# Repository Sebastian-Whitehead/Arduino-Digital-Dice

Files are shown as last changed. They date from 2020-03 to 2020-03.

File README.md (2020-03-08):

# DIY Digital Dice (d10000)

	This is an Arduino based DIY digital dice that, as standard, can generate a random number between 0 and 4 /6 /8 /10 /12 /20 /100 /1000 *or* 10000 along with a coin flip between heads and tails (1/2.) Using a gyroscope the device can sense its rotational acceleration around any one of the three axis and generate a random number when a specified threshold is reached. Originally created to use along side with an extended 'chaos magic' in DnD 5e. Despite this the dice can function as a physical random number generator for any situation with little modification to the Arduino code if wanted.

### Prerequisites

###### Software:

- Access to a 3d printer (... *cm* x ... *cm* x ... *cm*  **min print size**) and slicer
- 3D modelling program *(Fusion 360)*
- Arduino IDE *(or other Arduino compatible IDE's)*
  - LiquidCrystal.h
  - Wire.h
- EDA software Autodesk 'Eagle' *(alternatively 'Easy EDA')*

###### Components [Standard]:

- Arduino Nano
- 8x2 liquid crystal display
- MPU-6050 Gyroscope
- 2x 10k Resistor *THT*
- 1x 10k potentiometer 
- 2x 100nF non polarized capacitor (5.8mm *THT*) 
- 1x Speaker
- 2x Momentary Buttons <u>[hole mountable]</u> 
- 1x Toggle Switch / Button <u>[hole mountable]</u> 
- 1x 1s rechargeable Lithium Polymer battery and USB charging circuit 
  *<u>(Easily found from butchering a 5v battery charger)</u>*
- 1x PCB (*see production files*)
- 1x 3D printed shell
- (screws, nuts and washers) ...

### Contributing

All contributions are accepted with no requirements for permission from authors.

### Version

Release 0.1 **[Board Design & Program]** (08.03.2020)

### Authors

- **Sebastian Whitehead** - *Initial work* [*Version 1.0*]

### License

This Project is licensed under the MIT License - See the LICENSE.md file for details

### Acknowledgments

-  Dejan - howtomechatronics.com - parts of the Gyroscope code

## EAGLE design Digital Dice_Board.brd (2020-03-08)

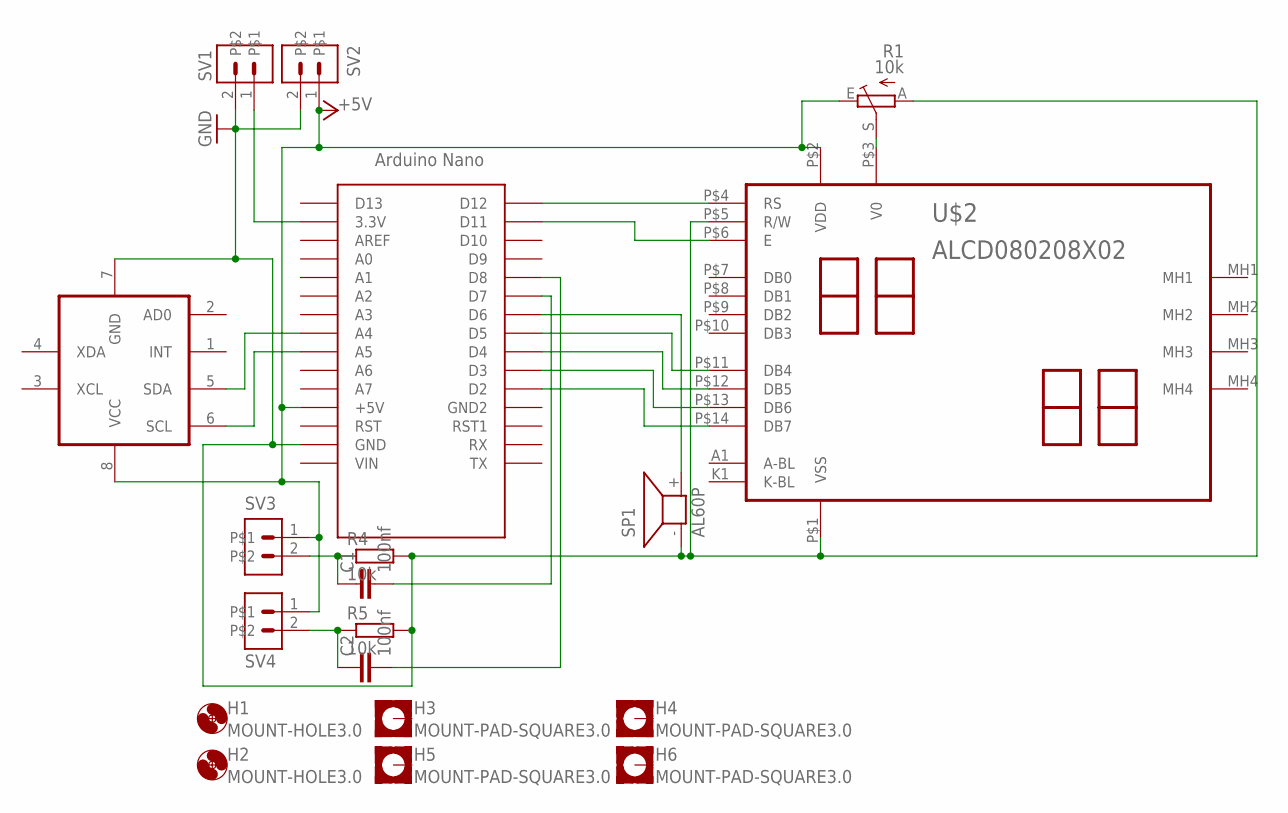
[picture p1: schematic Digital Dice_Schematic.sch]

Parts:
C1, C2: 100nf; C050-025X075W
H1, H2: MOUNT-HOLE3.0; 3,0
H3, H4, H5, H6: MOUNT-PAD-SQUARE3.0; 3,0-PAD-SQUARE
R1: 10k; CA9V
R4, R5: 10k; 0207/12
SP1: AL60P
SV1, SV2, SV3, SV4: MA02-1
U$1: NANO
U$2: ALCD080208X02; ALCD0802
X1: GYRO_MPU-6050; MPU

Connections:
+5V: R1.E, SV2.1, SV3.1, SV4.1, U$1.5V (+5V), U$2.P$2 (VDD), X1.8 (VCC)
GND: R1.A, R4.2, R5.2, SP1.- (1), SV1.2, SV2.2, U$1.GND, U$2.P$1 (VSS), U$2.P$5 (R/W), X1.7 (GND)
unnamed: U$1.D12, U$2.P$4 (RS)
unnamed: C2.1, R5.1, SV4.2
unnamed: U$1.A5, X1.6 (SCL)
unnamed: U$1.A4, X1.5 (SDA)
unnamed: R1.S, U$2.P$3 (V0)
unnamed: SV1.1, U$1.3.3V
unnamed: C1.1, R4.1, SV3.2
unnamed: U$1.D11, U$2.P$6 (E)
unnamed: U$1.D5, U$2.P$11 (DB4)
unnamed: U$1.D4, U$2.P$12 (DB5)
unnamed: U$1.D3, U$2.P$13 (DB6)
unnamed: U$1.D2, U$2.P$14 (DB7)
unnamed: SP1.+ (2), U$1.D6
unnamed: C1.2, U$1.D7
unnamed: C2.2, U$1.D8

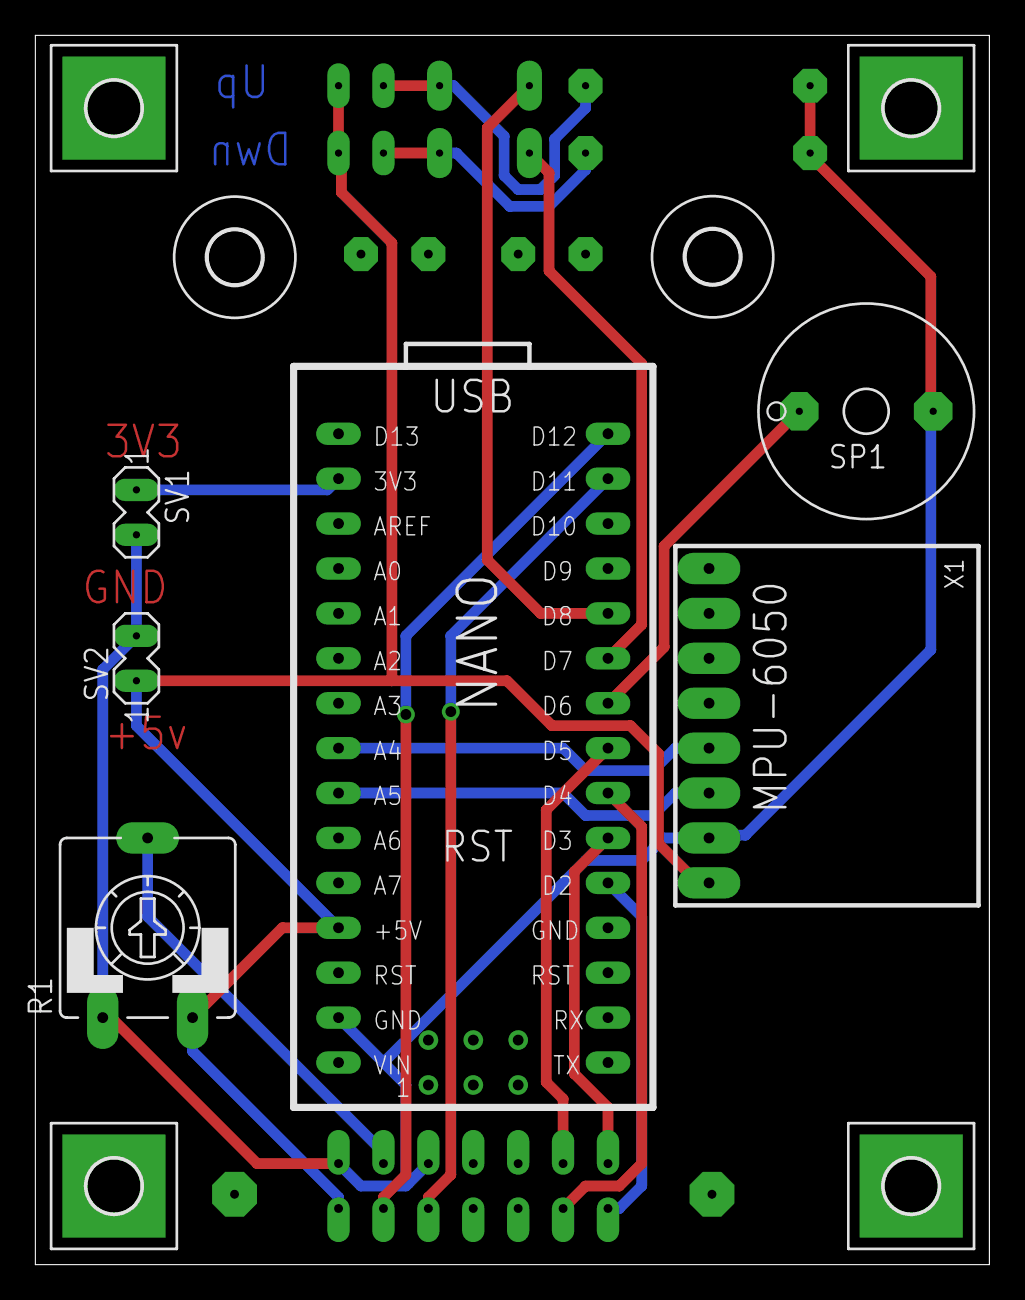
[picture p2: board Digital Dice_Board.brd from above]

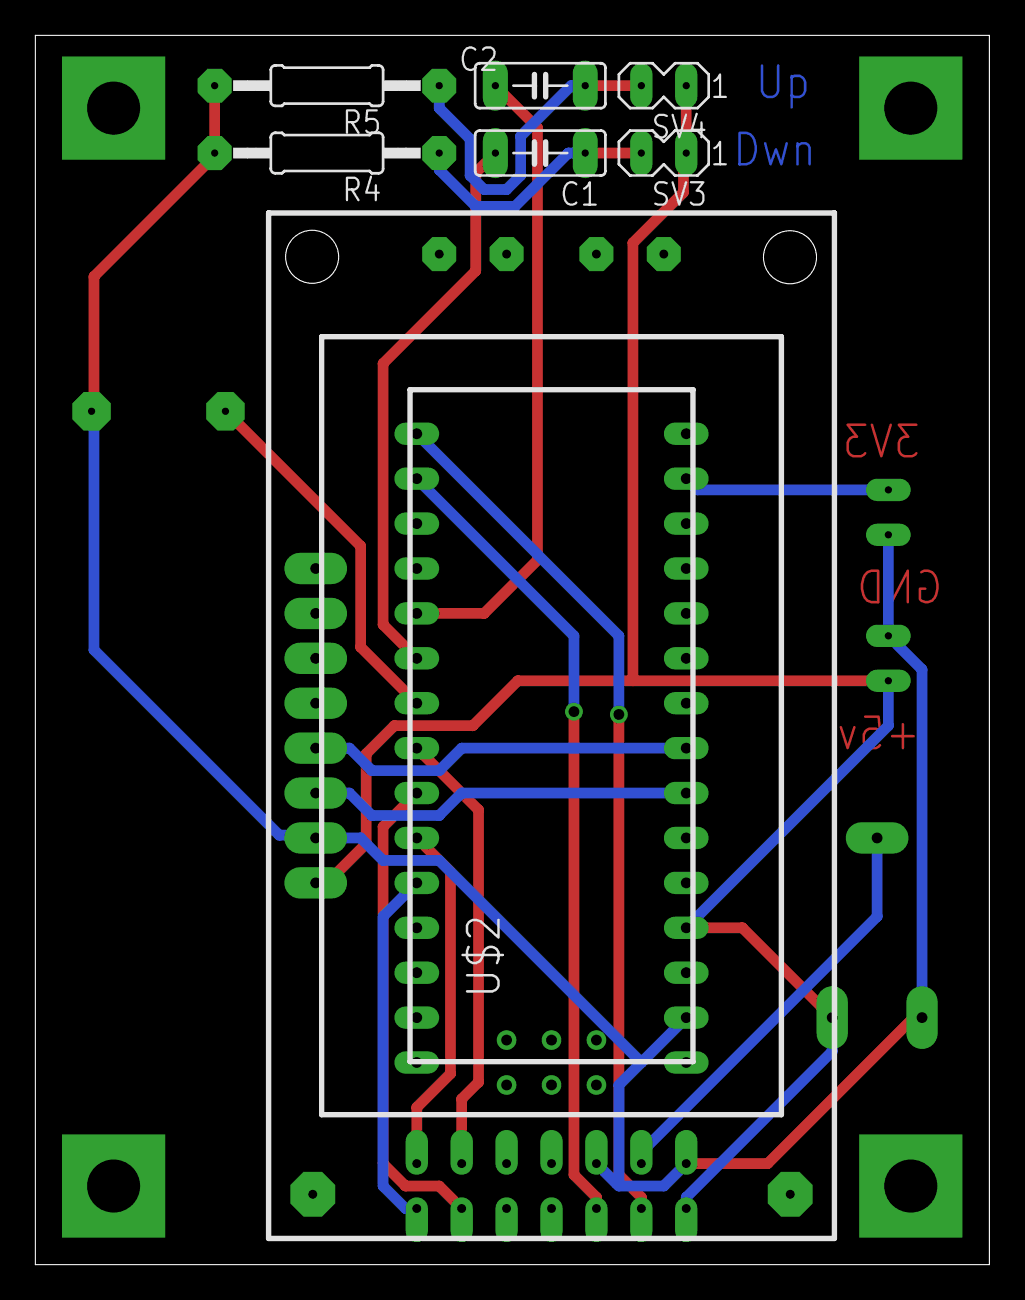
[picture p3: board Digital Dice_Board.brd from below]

Board: 2 copper layers, 54.0 x 69.5 mm, 19 parts (7 on the bottom side), 17 nets.

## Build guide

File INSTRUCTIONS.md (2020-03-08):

# Assembly Instructions

###### Tools

- Soldiering station (*possibly a hot air gun for heat shrink*)

- Screw driver and small wrench for mounting
- 3D printer (*alternatively order the model*)
- PC *with Arduino IDE installed*
- Mini-B USB cable
- Hot Glue Gun, Double Sided Tape & Zip Ties

###### Assembly

1. Order PCB using the included Gerber files 
2. Gather Compatible Electrical components for assembly 
   <u>(butcher a USB battery bank for the charging circuit)</u>
3. Modify the 3D model in order to accommodate you chosen components or as you see fit
4. Print the model components and gather the necessary mounting hardware  
5. If you have the tools to do so test the components before assembly with the 
   '*Digital Dice_ Arduino Program*'
6. Soldier all the components on the Arduino side of the board. 
7. Cut all excess leg length to make space for components on the other side of the board. 
8. Assemble and mount components on the opposite side of the PCB
   **NOTE: Put screws through the displays mounting holes with spacers in-between it and the PCB**
9. Adjust the screen contrast now as it will be difficult later
10. Mount the selection up and down buttons to the front panel and soldier their wires to the corresponding holes on the board
11. If necessary feed the power switch cables through the mounting hole 
    *(only necessary if the toggle switch is screwed in from the inside of the cube)*
12. Soldier the battery to the power switch and the corresponding 5v supply and ground holes on the PCB 
    *(There is 3v3 supply for backlit switches)*
13. Mount the PCB to the included screw holes making sure the black LCD bezel is aligned with the cut out 
14. Mount the power button and charging circuit to their corresponding locations.
15. Mount the LiPo battery cell to and adequate location
16. Charge, Power ON, Test
17.  **ENJOY!!** 

**WARNING!**	Make sure to take precautions when working with LiPo batteries as there are some inherent dangers that can arise. Preform this project at your own risk and if you make improvements or modifications for the project feel free to post them on the GitHub page for others to enjoy.

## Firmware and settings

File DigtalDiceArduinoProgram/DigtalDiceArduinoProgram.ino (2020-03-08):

/*
By: Sebastian Whitehead
Credit: Dejan (howtomechatronics.com) *Gyroscope code modified

==== Instructions ====
1. Shake to roll the dice (default d10000)
2. Use the buttons to cycle between the different dice types
3. To mute and unmute hold the selection up button until the 'Shake me' screen appears then release
4. Adjust the potentiometer to regulate text clarity

Distrobuted under the MIT license see LICENSE.md for more details
*/


#include <Wire.h>
#include <LiquidCrystal.h>

// == Pins == //
LiquidCrystal lcd(12, 11, 5, 4, 3, 2);
const int DownPin = 7;
const int UpPin = 8;
const int Speaker = 6;

// == Variables == //
const int MPU = 0x68;         // MPU6050 I2C address
float GyroX, GyroY, GyroZ;
long MaxRoll = 10001;         // Default Setting
int Dice = 9;                 // Number of dice types
long result = 0;              // Role result
unsigned long LastAction = 0; // Time of last screen effecting action
bool UpCompleted = false;     // Variables for preventing rapidly recurring presses
bool DownCompleted = false;
int MuteStart = 0;            // Start Time for mute function
int MuteStop = 0;             // Stop Time for mute function

// ==== Options ==== //
int IdleDelay = 30000;  // Standard delay before screen reverts to idle state
bool Mute = true; // Default Mute Setting



void setup() {
  Serial.begin(19200);
  pinMode(UpPin, INPUT);    //Button Pins
  pinMode(DownPin, INPUT);

  // Starting Gyro //
  Wire.begin();                      // Initialize comunication
  Wire.beginTransmission(MPU);       // Start communication with MPU6050 // MPU=0x68
  Wire.write(0x6B);                  // Talk to the register 6B
  Wire.write(0x00);                  // Make reset - place a 0 into the 6B register
  Wire.endTransmission(true);        // end the transmission
  delay(20);

  // Start LCD //
  lcd.begin(8, 2);

  // Starting Tune //
  tone(Speaker, 300);
  delay(250);
  tone(Speaker, 400);
  delay(250);
  tone(Speaker, 500, 250);
  idle(); // Idle Screen
}

void loop() {
  Gyro(); // Position sensing funktion
  if (millis() > LastAction + IdleDelay) { // Returns to idle after 30 seconds
    idle();
  }

  // ==== Push Button Up ==== //
  if (digitalRead(UpPin) == HIGH && UpCompleted == false) {
    Dice ++;
    Change();
    UpCompleted = true;
    MuteStart = millis();

    // ==== Release Button Up ==== //
  } else if (digitalRead(UpPin) == LOW && UpCompleted == true) {
    UpCompleted = false;
    MuteStop = millis();

    // == Long Press Mute Toggle == //
    if (MuteStop - MuteStart > 3000 && Mute == true) {
      Mute = false;
      lcd.clear();
      lcd.setCursor(0, 0);
      lcd.print("Unmuted");
    } else if (MuteStop - MuteStart > 3000 && Mute == false) {
      Mute = true;
      lcd.clear();
      lcd.setCursor(0, 0);
      lcd.print("  Muted");
    }
    IdleDelay = 3000;
    LastAction = millis();
  }

  // ==== Push Button Down ==== //
  if (digitalRead(DownPin) == HIGH && DownCompleted == false) {
    Dice --;
    Change();
    DownCompleted = true;

    // ==== Relase Button Up ==== //
  } else if (digitalRead(DownPin) == LOW) {
    DownCompleted = false;
  }
}

// === Read gyroscope data === //
void Gyro() {
  Wire.beginTransmission(MPU);
  Wire.write(0x43); // Gyro data first register address 0x43
  Wire.endTransmission(false);
  Wire.requestFrom(MPU, 6, true); // Read 4 registers total, each axis value is stored in 2 registers
  GyroX = (Wire.read() << 8 | Wire.read()) / 131.0; // For a 250deg/s range we have to divide first the raw value by 131.0, according to the datasheet
  GyroY = (Wire.read() << 8 | Wire.read()) / 131.0;
  GyroZ = (Wire.read() << 8 | Wire.read()) / 131.0;

  // Produces values for each rotation axsis between 0 -> 255
  GyroX = GyroX + 0.56; // GyroErrorX ~(-0.56)
  GyroY = GyroY - 2;    // GyroErrorY ~(2)
  GyroZ = GyroZ + 0.79; // GyroErrorZ ~ (-0.8)

  /*
    // Print the values on the serial monitor for testing
    Serial.print(GyroX);
    Serial.print("/");
    Serial.print(GyroY);
    Serial.print("/");
    Serial.println(GyroZ);
  */

  // === Roll Paramiters === //
  if (GyroX >= 250 || GyroY >= 240 || GyroZ >= 240 || GyroX <= -245 || GyroY <= -245 || GyroZ <= -245) {
    roll();
    LastAction = millis(); // Time for last roll
    IdleDelay = 30000;
  }
}

void idle() {
  // ==== Idle funktion ==== //
  lcd.clear();
  lcd.setCursor(0, 0);
  lcd.print("SHAKE");
  lcd.setCursor(0, 1);
  lcd.print("     ME!");
  LastAction = millis();
  IdleDelay = 30000;  //Reset Idle Timeout
}

void roll() {
  randomSeed(analogRead(0));    //Sets the seed for the random function to seconds since program start
  result = random(1, MaxRoll);  // 'Rolls The Dice'

  // ==== Rolling Animation + Sound ==== //
  lcd.clear();
  lcd.setCursor(0, 0);
  lcd.print("Rolling");
  Serial.println("Rolling"); // print for testing
  Serial.println("");
  delay(250);
  lcd.setCursor(0, 1);
  sound(350, 15);
  lcd.print(".");
  delay(250);
  sound(375, 15);
  lcd.print(".");
  delay(250);
  sound(400, 15);
  lcd.print(".");
  delay(250);
  sound(350, 15);
  lcd.setCursor(0, 1);
  lcd.print("        ");
  lcd.setCursor(0, 1);
  lcd.print(".");
  delay(250);
  sound(375, 15);
  lcd.print(".");
  delay(250);
  sound(400, 15);
  lcd.print(".");
  delay(500);
  lcd.clear();
  lcd.setCursor(0, 0);

  // === Heads / Tails for Coin === //
  if (Dice == 0) {
    if (result == 1) {
      lcd.print(" Heads");
    } else if (result == 2) {
      lcd.print(" Tails");
    }

    // === 'Result' Text Centering === //
  } else if (result < 100) {
    lcd.print("   ");
    lcd.print (result);
  } else {
    lcd.print ("  ");
    lcd.print (result);
  }
  sound(400, 200);
  delay(200);
  sound(500, 200);
}

// === Muteable Sound Function === //
void sound(int i, int n) {
  if (Mute == false) {
    tone(Speaker, i, n);
  }
}

// ==== Cycle Between Different Dice Types ==== //
void Change() {
  // == looping value == //
  if (Dice > 9) {
    Dice = 0;
  } else if (Dice < 0) {
    Dice = 9;
  }

  if (Dice == 0) {         // == Coin Flip == //
    MaxRoll = 2 + 1;
    lcd.clear();
    lcd.setCursor(0, 0);
    lcd.print("  Coin");

  } else if (Dice == 1) {  // == d4 == //
    MaxRoll = 4 + 1;
    lcd.clear();
    lcd.setCursor(0, 0);
    lcd.print("   d4");

  } else if (Dice == 2) {   // == d6 == //
    MaxRoll = 6 + 1;
    lcd.clear();
    lcd.setCursor(0, 0);
    lcd.print("   d6");

  } else if (Dice == 3) {   // == d8 == //
    MaxRoll = 8 + 1;
    lcd.clear();
    lcd.setCursor(0, 0);
    lcd.print("   d8");

  } else if (Dice == 4) {   // == d10 == //
    MaxRoll = 10 + 1;
    lcd.clear();
    lcd.setCursor(0, 0);
    lcd.print("   d10");

  } else if (Dice == 5) {   // == d12 == //
    MaxRoll = 12 + 1;
    lcd.clear();
    lcd.setCursor(0, 0);
    lcd.print("   d12");

  } else if (Dice == 6) {   // == d20 == //
    MaxRoll = 20 + 1;
    lcd.clear();
    lcd.setCursor(0, 0);
    lcd.print("   d20");

  } else if (Dice == 7) {   // == d100 == //
    MaxRoll = 100 + 1;
    lcd.clear();
    lcd.setCursor(0, 0);
    lcd.print("  d100");

  } else if (Dice == 8) {   // == d1000 == //
    MaxRoll = 1000 + 1;
    lcd.clear();
    lcd.setCursor(0, 0);
    lcd.print("  d1000");

  } else if (Dice == 9) {   // == d10000 == //
    MaxRoll = 10000 + 1;
    lcd.clear();
    lcd.setCursor(0, 0);
    lcd.print(" d10000");
  }

  LastAction = millis();
  IdleDelay = 3000; // Temporarily Reduce Idle Timeout
}
